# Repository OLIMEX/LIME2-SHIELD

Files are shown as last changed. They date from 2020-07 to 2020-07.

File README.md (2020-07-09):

# LIME2-SHIELD
Shield for A20-OLinuXino-LIME2 which adds Audio, CAN, microSD-card, 2x UEXT, CAN

Product page: https://www.olimex.com/Products/OLinuXino/A20/LIME2-SHIELD/open-source-hardware

## Licensee
* Hardware is released under CERN Open Hardware Licence Version 2 -
Strongly Reciprocal
* Software is released under GPL3 Licensee
* Documentation is released under CC BY-SA 3.0

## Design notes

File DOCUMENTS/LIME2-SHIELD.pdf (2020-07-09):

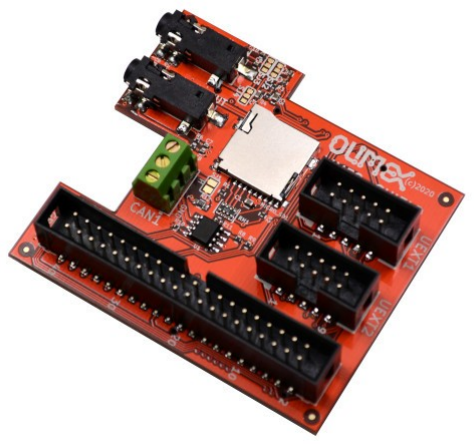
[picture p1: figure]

# LIME2-SHIELD

# User Manual

# Rev.1.0 June 2020

# olimex.com

## Table of Contents

This is possible only for the boards which has SPI Flash where uboot to be hold, as A20 can’t boot

Note that some interfaces are multiplexed with other functions and if you enable may distrub other

Now you have access to GPIO, SPI, I2C and Serial ports of A20-OLinuXino-LIME2 via Python

Next code switch on and off MOD-IO relays. MOD-IO should be connected to UEXT1. The code is

## What is LIME2-SHIELD

LIME2-SHIELD is small board which snaps on top of OLinuXino-LIME2 Linux computers and adds:
- Audio Headphone + microphone 3.5 mm connector
- Audio Line in / out connector
- Second micro SD card for data storage
- CAN driver and connector
- Two UEXT connectors with SERIAL, I2C, SPI available for users to connect UEXT modules
- 40 pin 0.1 breadboard friendly connector which can be used with IDC40 cable or Jumper wires Jwxxx

Audio-In

Headphones-Mic

UEXT-1

UEXT-2

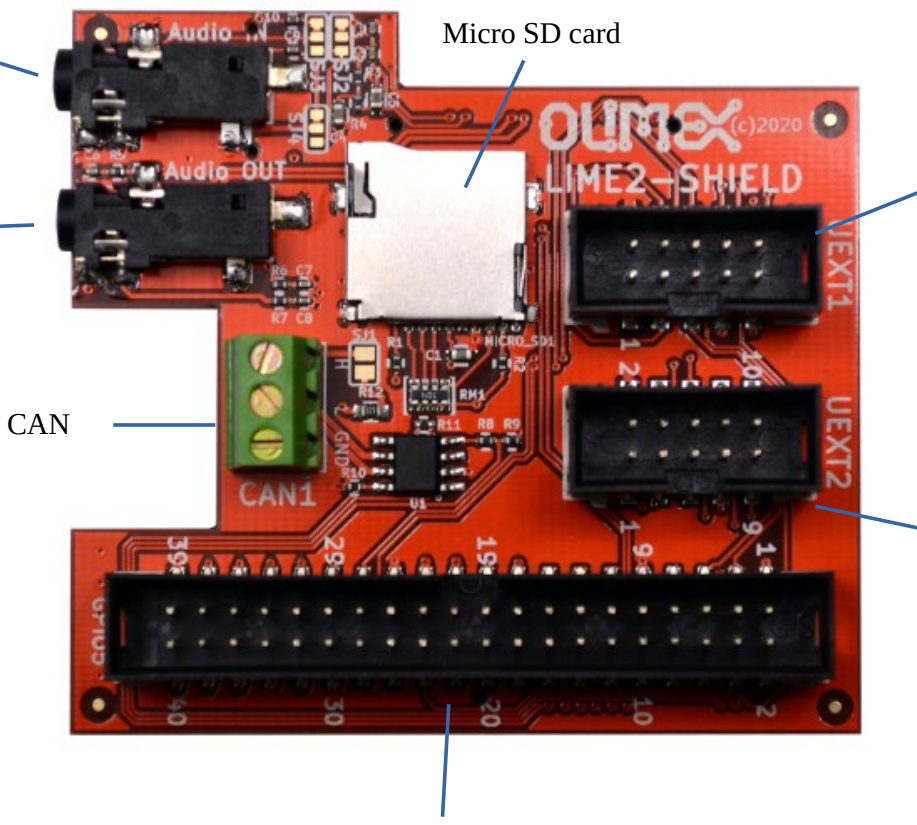
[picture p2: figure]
Micro SD card; CAN

GPIO-5

## Available signals and interfaces:

UEXT1
function | Int | Linux | A20 | A20 | Linux | Int | function
+3.3V | 1 | 2 | GND
UART4-TX | | GPIO202 | PG10 | 3 | 4 | PG11 | GPIO203 | UART4-RX
TWI2-SCL | | GPIO52 | PB20 | 5 | 6 | PB21 | GPIO53 | TWI2-SDA
SPI2-MISO | | GPIO86 | PC22 | 7 | 8 | PC21 | GPIO85 | SPI2-MOSI
SPI2-SCK | | GPIO84 | PC20 | 9 | 10 | PC19 | GPIO83 | SPI2-CS0

UEXT2
function | Int | Linux | A20 | A20 | Linux | Int | function
+3.3V | 1 | 2 | GND
UART7-TX | | GPIO276 | PI20 | 3 | 4 | PI21 | GPIO277 | | UART7-RX
TWI1-SCL | | GPIO50 | PB18 | 5 | 6 | PB19 | GPIO51 | | TWI1-SDA
SPI1-MISO | EINT31 | GPIO275 | PI19 | 7 | 8 | PI18 | GPIO274 | EINT30 | SPI1-MOSI
SPI1-SCK | EINT29 | GPIO273 | PI17 | 9 | 10 | PI16 | GPIO272 | EINT28 | SPI1-CS0

GPIO5
rPi | function | Int | Linux | A20 | A20 | Linux | Int | function | rPi
+3.3V | 1 | 2 | +5V
GPIO2 | TWI2-SDA | | GPIO53 | PB21 | 3 | 4 | +5V
GPIO3 | TWI2-SCL | | GPIO52 | PB20 | 5 | 6 | GND
GPIO4 | | | GPIO271 | PI15 | 7 | 8 | PG7 | GPIO199 | | UART3-RX | GPIO14
GND | | | | | 9 | 10 | PG6 | GPIO198 | | UART3-TX | GPIO15
GPIO17 | | EINT23 | GPIO267 | PI11 | 11 | 12 | PI3 | GPIO259 | | PWM1 | GPIO18
GPIO27 | | EINT22 | GPIO266 | PI10 | 13 | 14 | GND
GPIO22 | | | GPIO263 | PI7 | 15 | 16 | PE6 | GPIO136 | | | GPIO23
+3.3V | | | | | 17 | 18 | PE5 | GPIO135 | | | GPIO24
GPIO10 | SPI2-MOSI | | GPIO85 | PC21 | 19 | 20 | GND
GPIO9 | SPI2-MISO | | GPIO86 | PC22 | 21 | 22 | PE4 | GPIO132 | | | GPIO25
GPIO11 | SPI2-SCK | | GPIO84 | PC20 | 23 | 24 | PC19 | GPIO83 | | SPI2-CS0 | GPIO8
GND | | | | | 25 | 26 | PH14 | GPIO238 | EINT14 | | GPIO7
GPIO0 | TWI1-SDA | | GPIO51 | PB19 | 27 | 28 | PB18 | GPIO50 | | TWI1-SCL | GPIO1
GPIO5 | | | GPIO129 | PE1 | 29 | 30 | GND
GPIO6 | | | GPIO136 | PE8 | 31 | 32 | PH13 | GPIO237 | EINT13 | | GPIO12
GPIO13 | | | GPIO137 | PE9 | 33 | 34 | GND
GPIO19 | | | GPIO138 | PE10 | 35 | 36 | PH12 | GPIO236 | EINT12 | | GPIO16
GPIO26 | | | GPIO139 | PE11 | 37 | 38 | PH11 | GPIO235 | EINT11 | | GPIO20
GND | | | | | 39 | 40 | PH10 | GPIO234 | EINT10 | | GPIO21

## Linux images for SD card booting:

Olimex has it own image build scripts available at GitHub. (https://github.com/OLIMEX/olimage)
The pre-built and tested images can be found at: images.olimex.com. There are release and testing folders, use the stabile images from release only. Testing images are not tested completely and you can use on your own risk.
We support Ubuntu and Debian minimal and basic images. The list of the packages is in the .lst file. For all examples below we use Ubuntu minimal image (http://images.olimex.com/release/a20/) .
To make your own SD card download the image and un-archive it with 7z archiver. (https://www.7-zip.org/)
Do not use DD for image write to SD-card, use balenaEtcher (https://www.balena.io/etcher/) to write the image to minimum 8GB Class 10 SD card like this one. (https://www.olimex.com/Products/Components/Storage/MICRO-SD-CLASS10/)
We strongly suggest you to use Olimex official images as they are 100% tested and know to work with all board features.
If you have USB cable you can insert it to USB-OTG connector of A20-OLinuXino-LIME2 and run any serial terminal:

### $ sudo minicom -D /dev/ttyACM0

Initial login is user: root or olimex, password: olimex
When new Linux image is released you do not need to download the image and write to the card, but only to run:

### $ sudo apt update $ sudo apt upgrade $ sudo reboot now

This way you will have always the latest version of Linux kernel and uboot.

## Boot from eMMC:

If you have A20-OLinuXino-LIME2 with eMMC memory you can make your boot from eMMC instead of SD-card to do this you have to boot from SD-card then execute:

### $ olinuxino-sd-to-emmc

after the script finish the SD-card image is copied to eMMC, then remove the SD-card and reboot.

## Boot from SATA:

This is possible only for the boards which has SPI Flash where uboot to be hold, as A20 can’t boot from SATA directly.
When you boot from SD-card you run:

### $ olinuxino-sd-to-sata

This script will write uboot to SPI Flash and Linux file system to SATA drive.

## Linux overlays:

To enable the different interfaces use:

### $ olinuxino-overlay

This will give you access to all overlays for the board.
Note that some interfaces are multiplexed with other functions and if you enable may distrub other functionality.

All overlays do not fit on single screen so you have to scroll down to see all options.

## Display overlays:

You can use olinuxino-display script to select your default LCD display.

### $ olinuxino-display

## Installing C:

The minimal Linux image comes with no C compiler installed so you need to install yourself:

### $ sudo apt install gcc

then you can compile your c code with

### $ gcc test.c -o program

and allow program to be executed:

### $ chmod +777 program

then run it with

### $ ./program

## Installing pyA20Lime2:

First you need to install Python

### $ sudo apt install python3 $ sudo apt install python3-venv python3-pip $ python3 -m pip install --upgrade pip setuptools wheel $ sudo su # pip3 install pyA20Lime2

Now you have access to GPIO, SPI, I2C and Serial ports of A20-OLinuXino-LIME2 via Python package pyA20Lime2. (https://pypi.org/project/pyA20Lime2/)

## Software access to board resources:

## GPIO in command line:

GPIOs are digital inputs or outputs which are available for the user. By default none of them is enabled. You can see the available GPIOs with the command:

### $ls sys/class/gpio

to enable GPIO you have to export it and to assign it as input or output
Let for example attach LED to GPIO5 connector pin.7 A20 port PI15 and GPIO5 connector pin.9 (GND). We need to connect negative (cathode) lead of the LED to GND (GPIO5.pin9) and the positive LED positive (anode) lead through 470 ohm resistor to A20.PI15 (GPIO5.pin7). The 470 ohm resistor is necessary to limit the current which will flow through LED.
Here is picture of our setup:

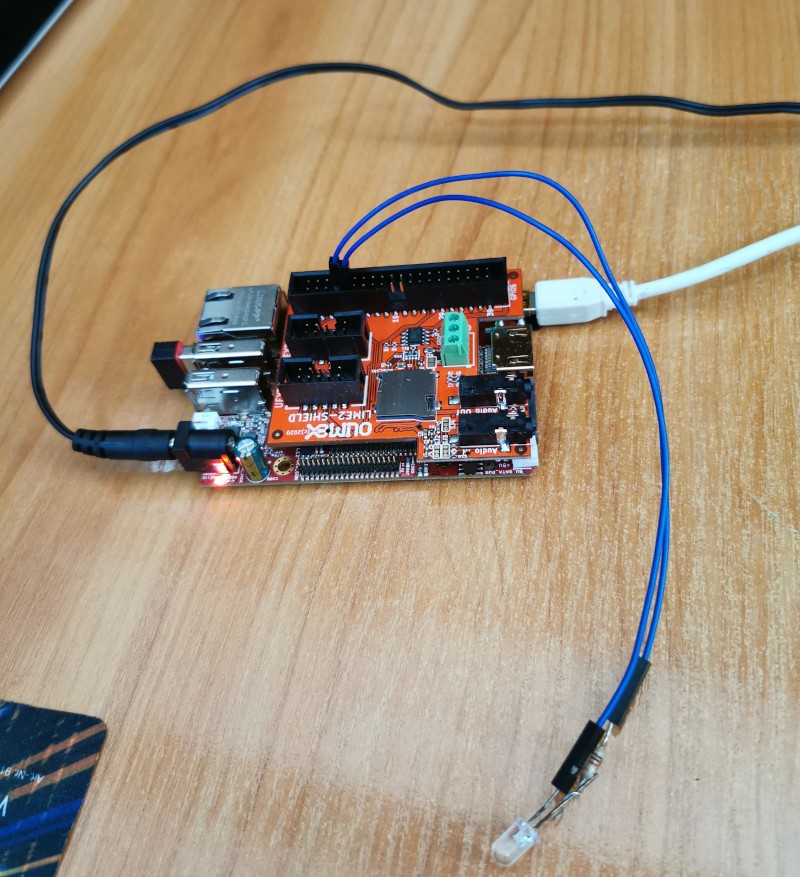
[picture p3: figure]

Now to light on the LED we have to export A20.PI15 then to make it output and write 1 in it which will bring 3.3V to the A20.PI15 pin which voltage will light the LED on.
To deal with the GPIOs we need to have superuser rights, so we start with:

### $ sudo su

we will be asked for the password, then the prompt will change to #

### # echo 271 > /sys/class/gpio/export

now we can check if gpio271 is already available with

### # ls sys/class/gpio

and we see the gpio271 is already listed now we have to define it as output:

### # echo out > /sys/class/gpio/gpio271/direction

now we have GPIO271 defined as output we can change it state with

### # echo 1 > /sys/class/gpio/gpio271/value

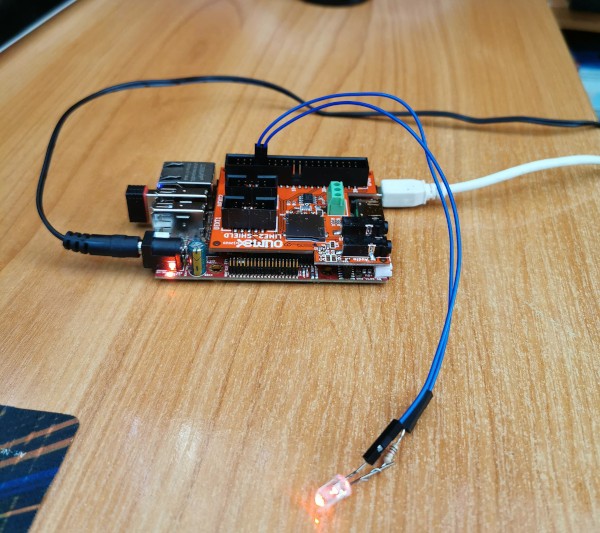
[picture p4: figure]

And the LED is lighting:

to turn if off we type

### # echo 0 > /sys/class/gpio/gpio271/value

Let now make GPIO271 as input

### # echo in > /sys/class/gpio/gpio271/direction

let connect A20.PI15 GPIO5.pin7 to GND GPIO5.pin9 :

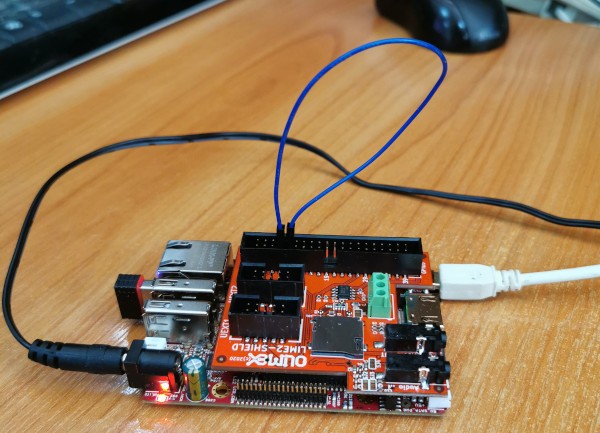
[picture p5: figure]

now we check the value with:

### #cat /sys/class/gpio/gpio271/value

we see 0. If we connect A20.PI15 GPIO5.pin7 to 3.3V GPIO5.pin17 and execute again cat command we see 1
Where the number 271 comes from? It’s Linux numbering the number corresponding to the port is calculated as PA starts from 0, PB starts from 32,... PI is staring from 8*32 = 256 so PI15 is 256+15 = 271

## GPIO with C code:

Here below is example how to drive GPIOs in C code. The sources are available on GitHub.

### include <stdio.h> #include <fcntl.h> #include <string.h>

### int main() {

char s_out[] = "out";
char s_gpio[] = "271";
char s_0[] = "0";
char s_1[] = "1";
int fd;

### //export GPIO271

### if((fd=open("/sys/class/gpio/export",O_WRONLY))<0) {

printf("can't open export GPIO\r\n"); return(1);

### } else { if(write(fd,s_gpio,strlen(s_gpio))<0) {

printf("can't write to export GPIO\r\n"); return(1);
}
printf("GPIO271 is exported\r\n");

### if(close(fd)<0) {

printf("can't close export GPIO\r\n"); return(1);
}
}

### //set as output GPIO271

### if((fd=open("/sys/class/gpio/gpio271/ direction",O_WRONLY))<0) {

printf("can't open GPIO direction\r\n"); return(1);

### } else { if(write(fd,s_out,strlen(s_out))<0) {

printf("can't write GPIO direction\r\n"); return(1);
}
printf("GPIO271 is set as output\r\n");

### if(close(fd)<0) {

printf("can't close GPIO direction\r\n"); return(1);
}
}

### //toggle GPIO271

### if((fd=open("/sys/class/gpio/gpio271/value",O_WRONLY))<0) {

printf("can't open GPIO value\r\n");
return(1);

### } else {

### while(1) {

### if(write(fd,s_1,strlen(s_1))<0) {

printf("can't write GPIO value\r\n"); return(1);
}

### if(write(fd,s_0,strlen(s_0))<0) {

printf("can't write GPIO value\r\n"); return(1);
}
};

### if(close(fd)<0)

return(1);
}

}

## GPIO with Python:

Let use same setup LED connected to GPIO5 connector pin.7 A20 port PI15 and GPIO5 connector pin.9 (GND). We need to connect negative (cathode) lead of the LED to GND (GPIO5.pin9) and the positive LED positive (anode) lead through 470 ohm resistor to A20.PI15 (GPIO5.pin7). The 470 ohm resistor is necessary to limit the current which will flow through LED.

### !/usr/bin/env python from pyA20Lime2.gpio import gpio from pyA20Lime2.gpio import port from pyA20Lime2.gpio import connector

### gpio.init() #Initialize module. Always called first

### gpio.setcfg(port.PI15, gpio.OUTPUT) #Configure LED1 as output

gpio.setcfg(port.PI15, 1) | #This is the same as

### above

### gpio.output(port.PI15, gpio.HIGH) #Set PI15 High (3.3V) and Light on LED

gpio.output(port.PI15, 1) | #same as above
gpio.output(port.PI15, gpio.LOW) | #Set PI15 Low (0V)

### Light off

gpio.output(port.PI15, 0) | #same as above
gpio.setcfg(port.PI15, gpio.INPUT) | #Configure PI15 as

### input

gpio.setcfg(port.PI15, 0) | #Same as above
gpio.pullup(port.PI15, 0) | #Clear pullups

### gpio.pullup(port.PI15, gpio.PULLDOWN) #Enable pull-down gpio.pullup(port.PI15, gpio.PULLUP) #Enable pull-up

### if gpio.input(port.PI15) == 1: # this will be executed when input is HIGH i.e. 3.3V else: # this will be executed when input is LOW i.e. 0V

## I2C in command line

You can detect where your device is connected by using i2cdetect command. For instance if you have connected MOD-IO to UEXT1 connector and run i2cdetect you will see it’s address 0x58 active:

### $ sudo i2cdetect -r -y 2 0 1 2 3 4 5 6 7 8 9 a b c d e f

00: | -- -- -- -- -- -- -- -- -- -- -- -- --
10: -- -- -- -- -- -- -- -- -- -- -- -- -- -- -- --20: -- -- -- -- -- -- -- -- -- -- -- -- -- -- -- --30: -- -- -- -- -- -- -- -- -- -- -- -- -- -- -- --40: -- -- -- -- -- -- -- -- -- -- -- -- -- -- -- --50: -- -- -- -- -- -- -- -- 58 -- -- -- -- -- -- --60: -- -- -- -- -- -- -- -- -- -- -- -- -- -- -- --70: -- -- -- -- -- -- -- --

### Then you can drive relays on and off:

### $ sudo i2cset -y 2 0x58 0x10 0x01

this will swtich on RELAY1, to switch it off:

### $ sudo i2cset -y 2 0x58 0x10 0x00

if you want to read MOD-IO status you can use i2transfer:

### $ sudo i2ctransfer -y 2 w1@0x58 0x20 r1

0x00

Now connect wire from IN1 left side to GND (for instance AIN-2 connector has AGND) and right side to +3.3-12V for instance AIN-2 connector has 3.3V)
if you run again i2ctransfer command the returned value will be 0x01:

### $ sudo i2ctransfer -y 2 w1@0x58 0x20 r1

0x01

## I2C in C code

Here is example how to use I2C with C. The source is available on GitHub. main.c

### include <stdio.h> #include <linux/i2c.h> #include <linux/i2c-dev.h> #include <fcntl.h> #include <stdlib.h> #include <unistd.h> #include <sys/ioctl.h> #include <string.h> #include "i2c.h"

### int main(int argc, char **argv)

{

### //switch on MOD-IO relay 1

int file;
unsigned char buffer[2], address;

address = 0x58;
buffer[0] = 0x10;
buffer[1] = 0x01;
I2C_Open(&file, address);
I2C_Send(&file, buffer, 2); I2C_Close(&file);

return 0;
}

i2c.c

### include <stdio.h> #include <linux/i2c.h> #include <linux/i2c-dev.h> #include <fcntl.h> #include <stdlib.h> #include <unistd.h> #include <sys/ioctl.h>

### #include <string.h>

### void I2C_Open(int *file, unsigned char address)

{
*file = (int)open("/dev/i2c-2", O_RDWR);

### if(*file < 0)

{
perror("Failed to open I2C"); exit(1);
}

### else

{

### if(ioctl(*file, I2C_SLAVE, address) < 0)

{
perror("Failed to access I2C bus"); exit(1);
}
}
}

### void I2C_Close(int *file)

{
close(*file);
}

### void I2C_Send(int *file, char *buffer, int num)

{
int bytes;
bytes = write(*file, buffer, num);

### if(bytes != num)

{
perror("Failed to send data"); exit(1);
}
}

### void I2C_Read(int *file, unsigned char *buffer, int num)

{
int bytes;
bytes = read(*file, buffer, num);

### if(bytes != num)

{
perror("Failed to read data"); exit(1);
}
}

i2c.h

### ifndef I2C_H #define I2C_H

void I2C_Open(int *file, unsigned char address);
void I2C_Send(int *file, unsigned char *buffer, int num); void I2C_Read(int *file, unsigned char *buffer, int num); void I2C_Close(int *file);

### #endif

makefile

### CC = gcc CFLAG = -c -Wall

### all: i2c-demo

### i2c-demo: i2c.o main.o $(CC) i2c.o main.o -o mod-io

### main.o: main.c $(CC) $(CFLAG) main.c

### i2c.o: i2c.c $(CC) $(CFLAG) i2c.c

### clean: rm -rf *.o i2c-demo

## I2C in Python

Next code switch on and off MOD-IO relays. MOD-IO should be connected to UEXT1. The code is available on GitHub.

### from pyA20Lime2 import i2c i2c.init("/dev/i2c-2")

### i2c.open(0x58) i2c.write([0x10, 0x01]) # switich ON relay1 i2c.close()

### i2c.open(0x58) i2c.write([0x10, 0x00]) # switich OFF relay1 i2c.close()

### i2c.open(0x58)

i2c.write([0x20]) | # read IN1..4 state

### value = i2c.read(1) i2c.close()

## CAN in command line

LIME2-SHIELD has CAN driver so you can connect to CAN bus.

### $ ifconfig -a can0: flags=128<NOARP> mtu 16 unspec 00-00-00-00-00-00-00-00-00-00-00-00-00-00-00-00 txqueuelen 10 ) RX packets 0 bytes 0 (0.0 B) RX errors 0 dropped 0 overruns 0 frame 0 TX packets 0 bytes 0 (0.0 B) TX errors 0 dropped 0 overruns 0 carrier 0 collisions 0 device interrupt 59

To use CAN interface you can install can-utils and setup the CAN interface:

### $ sudo apt-get install can-utils $ ip link set can0 down $ ip link set can0 type can bitrate 100000 triple-sampling on loopback off $ ip link set can0 up

Now conect A20-CAN to the CAN network two wire interface.

To send a packet over CAN use :

### cansend <can_interface> <packet>

### For instance:

### $ cansend can0 5AA#10.10.10

To sniff for CAN network messages you can use candump :

### $ candump can0

Now you can log your car CAN networking messages and interpret them. There is plenty of info on the web about the different CAN messages which are exchanged on car CAN bus.

## CAN in C code

Kernel code documentation https://www.kernel.org/doc/Documentation/networking/can.txt C code Examples from GitHub (https://github.com/craigpeacock/CAN-Examples)
cansend.c

#include <stdio.h>

#include <stdlib.h>

#include <string.h>

#include <unistd.h>

#include <net/if.h>

#include <sys/ioctl.h>

#include <sys/socket.h>

#include <linux/can.h>

#include <linux/can/raw.h>

int main(int argc, char **argv) {
int s;
struct sockaddr_can addr;
struct ifreq ifr;
struct can_frame frame;

printf("CAN Sockets Demo\r\n");

if ((s = socket(PF_CAN, SOCK_RAW, CAN_RAW)) < 0) { perror("Socket");
return 1;
}

strcpy(ifr.ifr_name, "can0" ); ioctl(s, SIOCGIFINDEX, &ifr);

memset(&addr, 0, sizeof(addr));
addr.can_family = AF_CAN;
addr.can_ifindex = ifr.ifr_ifindex;

if (bind(s, (struct sockaddr *)&addr, sizeof(addr)) < 0) { perror("Bind");
return 1;
}

frame.can_id = 0x555;
frame.can_dlc = 5;
sprintf(frame.data, "Hello");

if (write(s, &frame, sizeof(struct can_frame)) != sizeof(struct can_frame)) { perror("Write");
return 1;
}

if (close(s) < 0) {
perror("Close");
return 1;
}

return 0;
}

canreceive.c

#include <stdio.h>

#include <stdlib.h>

#include <string.h>

#include <unistd.h>

#include <net/if.h>

#include <sys/ioctl.h>

#include <sys/socket.h>

#include <linux/can.h>

#include <linux/can/raw.h>

int main(int argc, char **argv) {
int s, i;
int nbytes;
struct sockaddr_can addr;
struct ifreq ifr;
struct can_frame frame;

printf("CAN Sockets Receive Demo\r\n");

if ((s = socket(PF_CAN, SOCK_RAW, CAN_RAW)) < 0) { perror("Socket");
return 1;
}

strcpy(ifr.ifr_name, "can0" ); ioctl(s, SIOCGIFINDEX, &ifr);

memset(&addr, 0, sizeof(addr));
addr.can_family = AF_CAN;
addr.can_ifindex = ifr.ifr_ifindex;

if (bind(s, (struct sockaddr *)&addr, sizeof(addr)) < 0) { perror("Bind");
return 1;
}

nbytes = read(s, &frame, sizeof(struct can_frame));

if (nbytes < 0) {
perror("Read");
return 1;
}

printf("0x%03X [%d] ",frame.can_id, frame.can_dlc);

for (i = 0; i < frame.can_dlc; i++)
printf("%02X ",frame.data[i]);

printf("\r\n");

if (close(s) < 0) {
perror("Close");
return 1;
}

return 0;
}

## SPI in Python

SPI communication in Python:

### #!/usr/bin/env python

### from pyA20Lime2 import spi

### spi.open("/dev/spidev2.0") #Open SPI device with default settings # mode : 0 # speed : 100000kHz # delay : 0 # bits-per-word: 8

### Different ways to open device spi.open("/dev/spidev2.0", mode=1) spi.open("/dev/spidev2.0", mode=2, delay=0)

spi.open("/dev/spidev2.0", mode=3, delay=0,

### bits_per_word=8)

spi.open("/dev/spidev2.0", mode=0, delay=0,

### bits_per_word=8, speed=100000)

### spi.write([0x01, 0x02]) #Write 2 bytes to slave device spi.read(2) #Read 2 bytes from slave device spi.xfer([0x01, 0x02], 2) #Write 2 byte and then read 2

bytes.

### spi.close() #Close SPI bus

## Revision History

Revision 1.0 June 2020

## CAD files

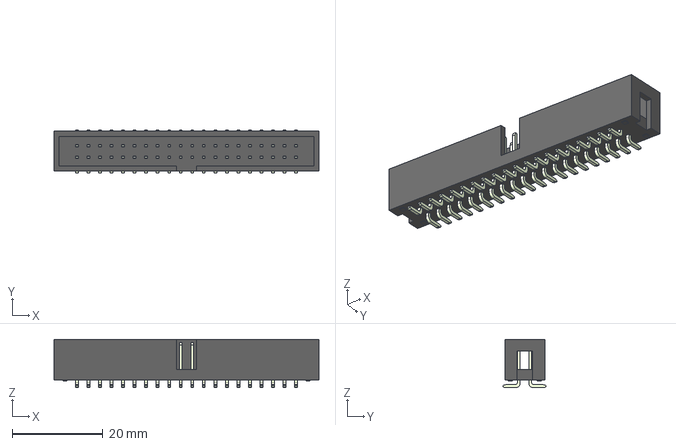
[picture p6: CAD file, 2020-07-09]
HARDWARE/Lime2-SHIELD-Rev.C/3d/GBH254SMT-40(B-V-40-LF).stp
58.4 x 9.50 x 10.6 mm

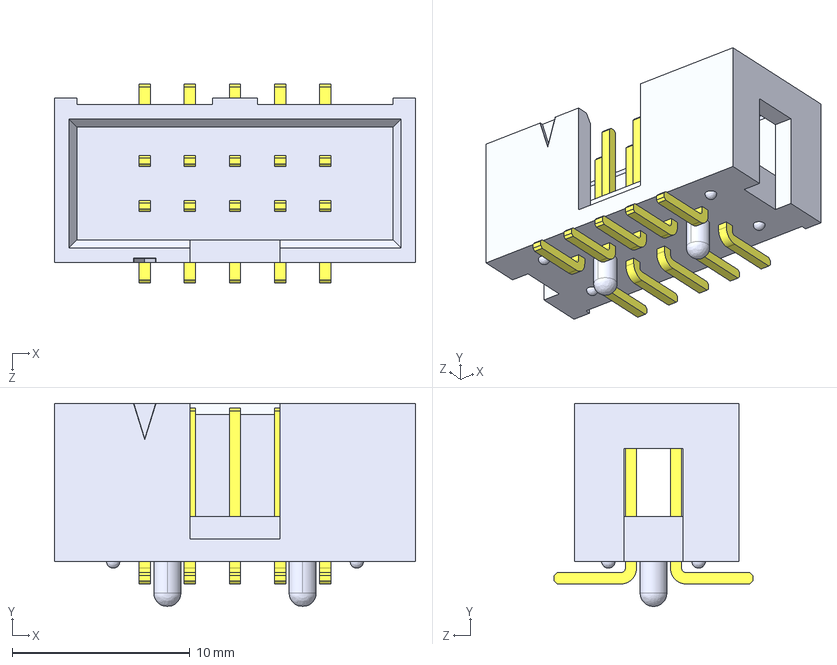
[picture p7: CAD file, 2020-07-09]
HARDWARE/Lime2-SHIELD-Rev.C/3d/UEXT-SMD.STEP
20.3 x 11.4 x 11.2 mm
User Library-HTST-105-01-F-DV-A__HTST-105-01-DV-A_header
User Library-HTST-105-01-F-DV-A__HTST-First_Position_Indicator
User Library-HTST-105-01-F-DV-A__T-1S6-05-01-DV_

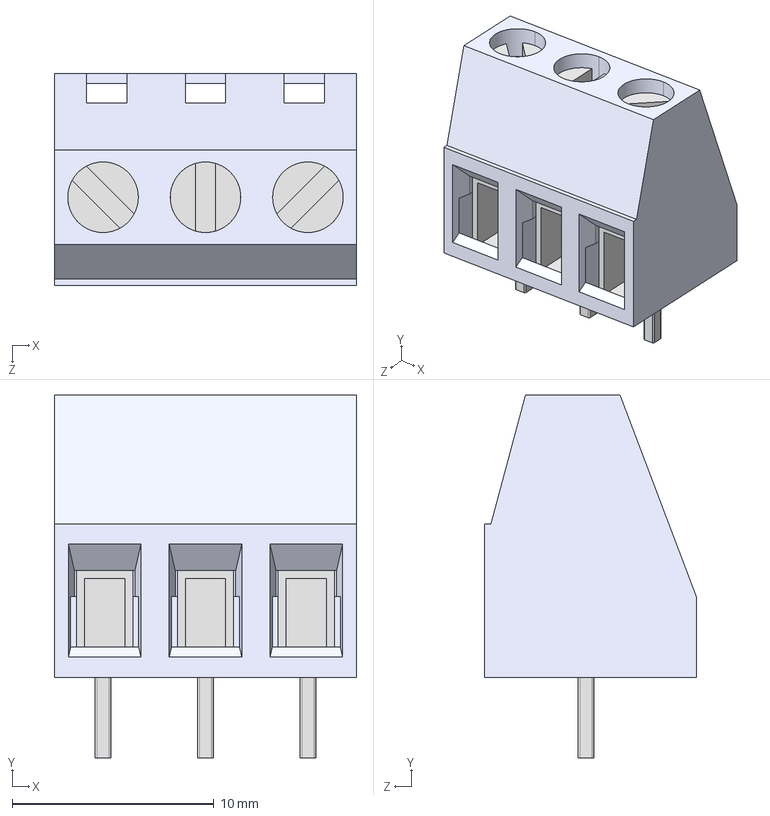
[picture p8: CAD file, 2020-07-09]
HARDWARE/Lime2-SHIELD-Rev.C/3d/klema-5mm-3pin.step
15.0 x 18.0 x 10.5 mm

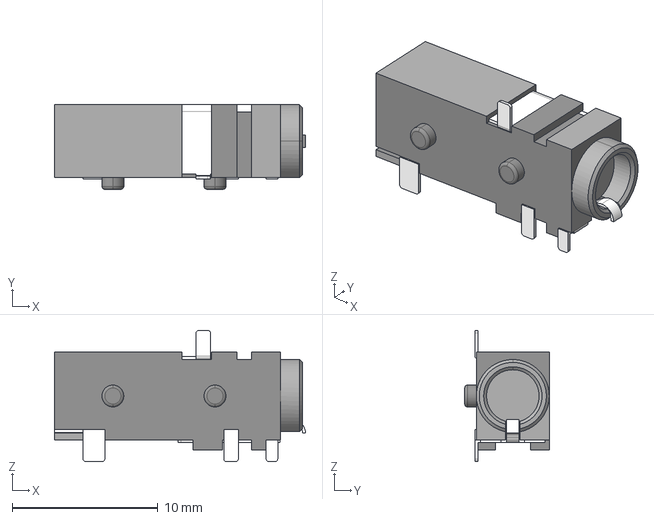
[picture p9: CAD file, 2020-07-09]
HARDWARE/Lime2-SHIELD-Rev.C/3d/sj-43514-smt-tr.stp
17.2 x 5.80 x 9.00 mm

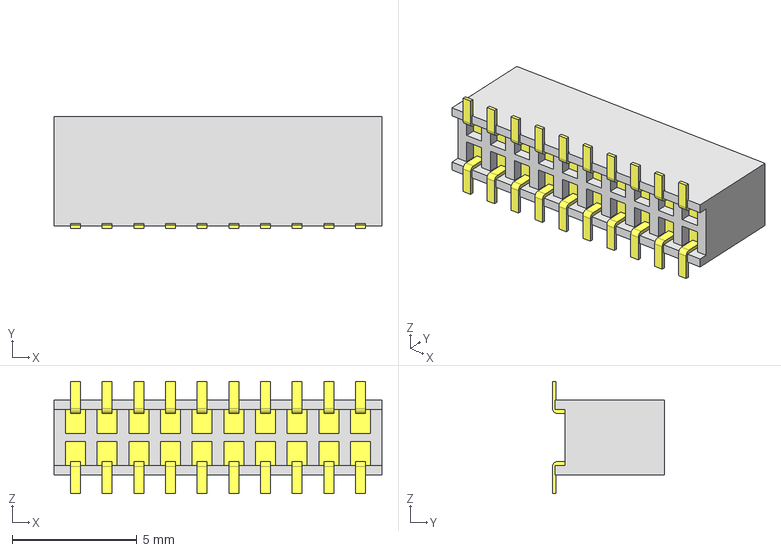
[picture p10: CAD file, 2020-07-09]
HARDWARE/Lime2-SHIELD-Rev.C/3d/YA-V36P-2X10-Amphenol_ICC(FCI)_20021321-00020T4LF.stp
13.2 x 4.50 x 4.50 mm
_20021321-00020T4LF_body
_20021321-00020T4LF_pins

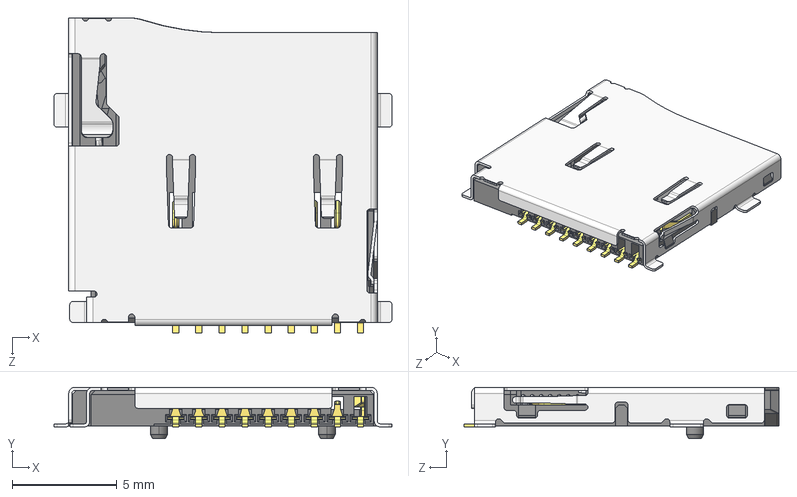
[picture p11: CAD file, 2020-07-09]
HARDWARE/Lime2-SHIELD-Rev.C/3d/TFC-WPAPR-08---112J-TXAR-R_C_1-1.STEP
16.1 x 2.45 x 15.0 mm

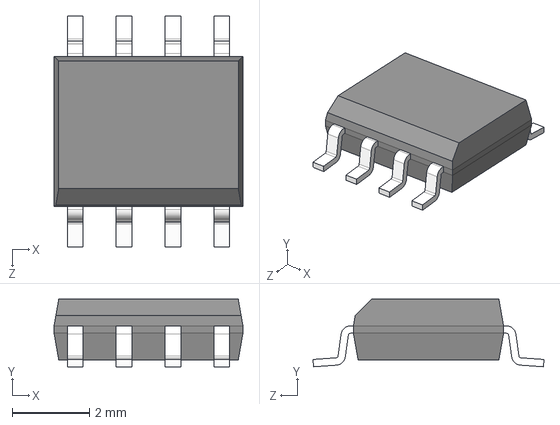
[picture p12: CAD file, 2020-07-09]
HARDWARE/Lime2-SHIELD-Rev.C/3d/SO-8_150mil---SN65HVDA1050AQDRQ1.STEP
4.90 x 1.75 x 5.99 mm

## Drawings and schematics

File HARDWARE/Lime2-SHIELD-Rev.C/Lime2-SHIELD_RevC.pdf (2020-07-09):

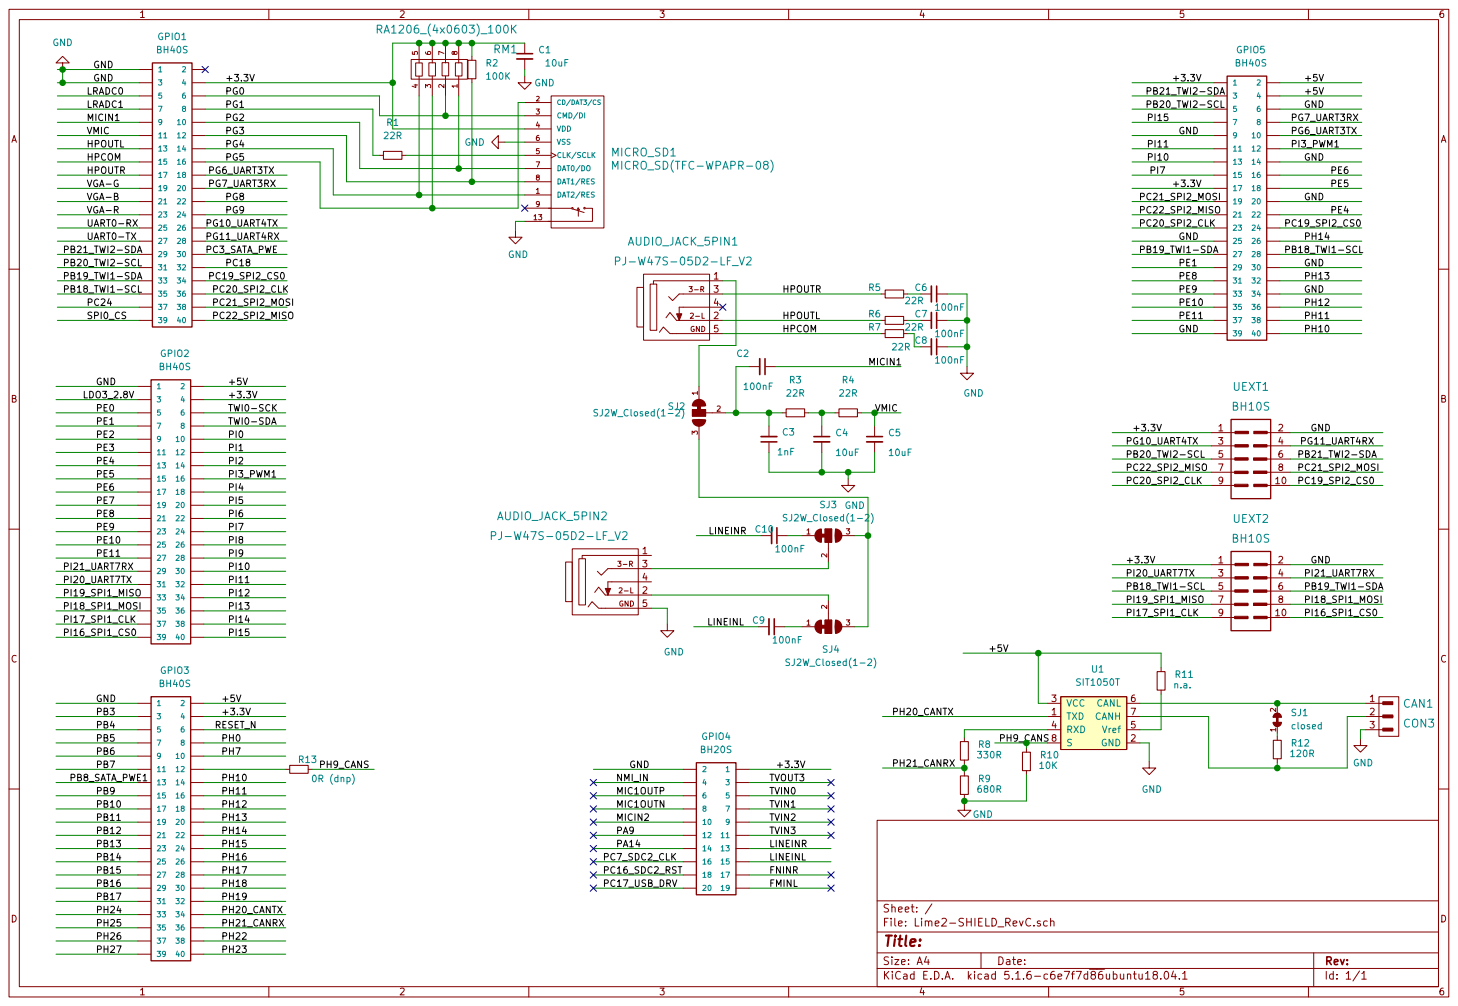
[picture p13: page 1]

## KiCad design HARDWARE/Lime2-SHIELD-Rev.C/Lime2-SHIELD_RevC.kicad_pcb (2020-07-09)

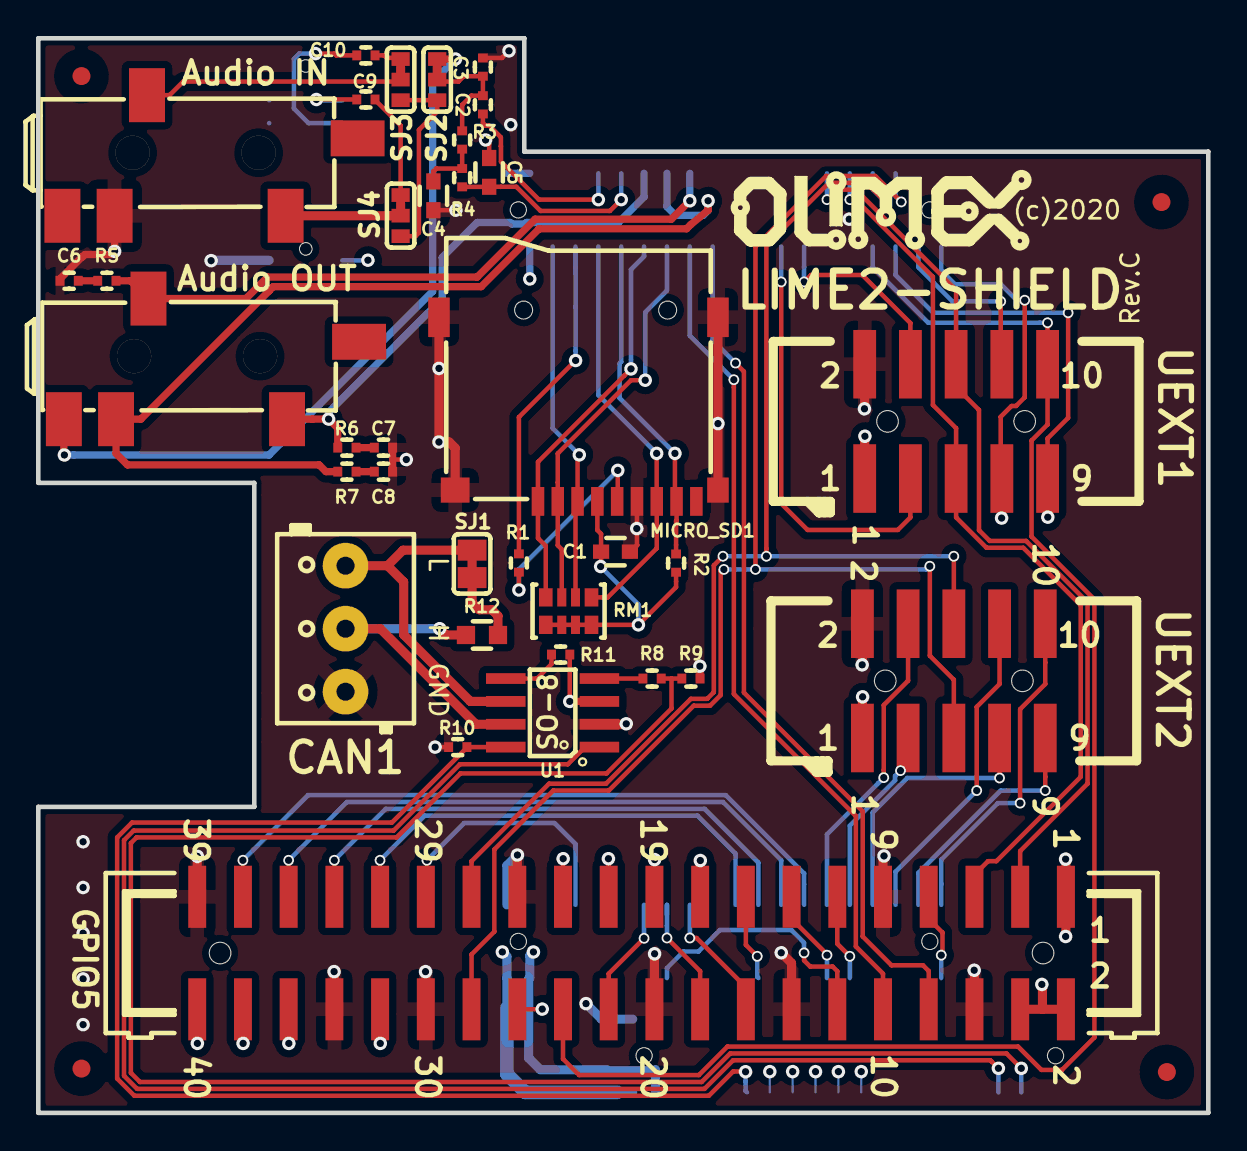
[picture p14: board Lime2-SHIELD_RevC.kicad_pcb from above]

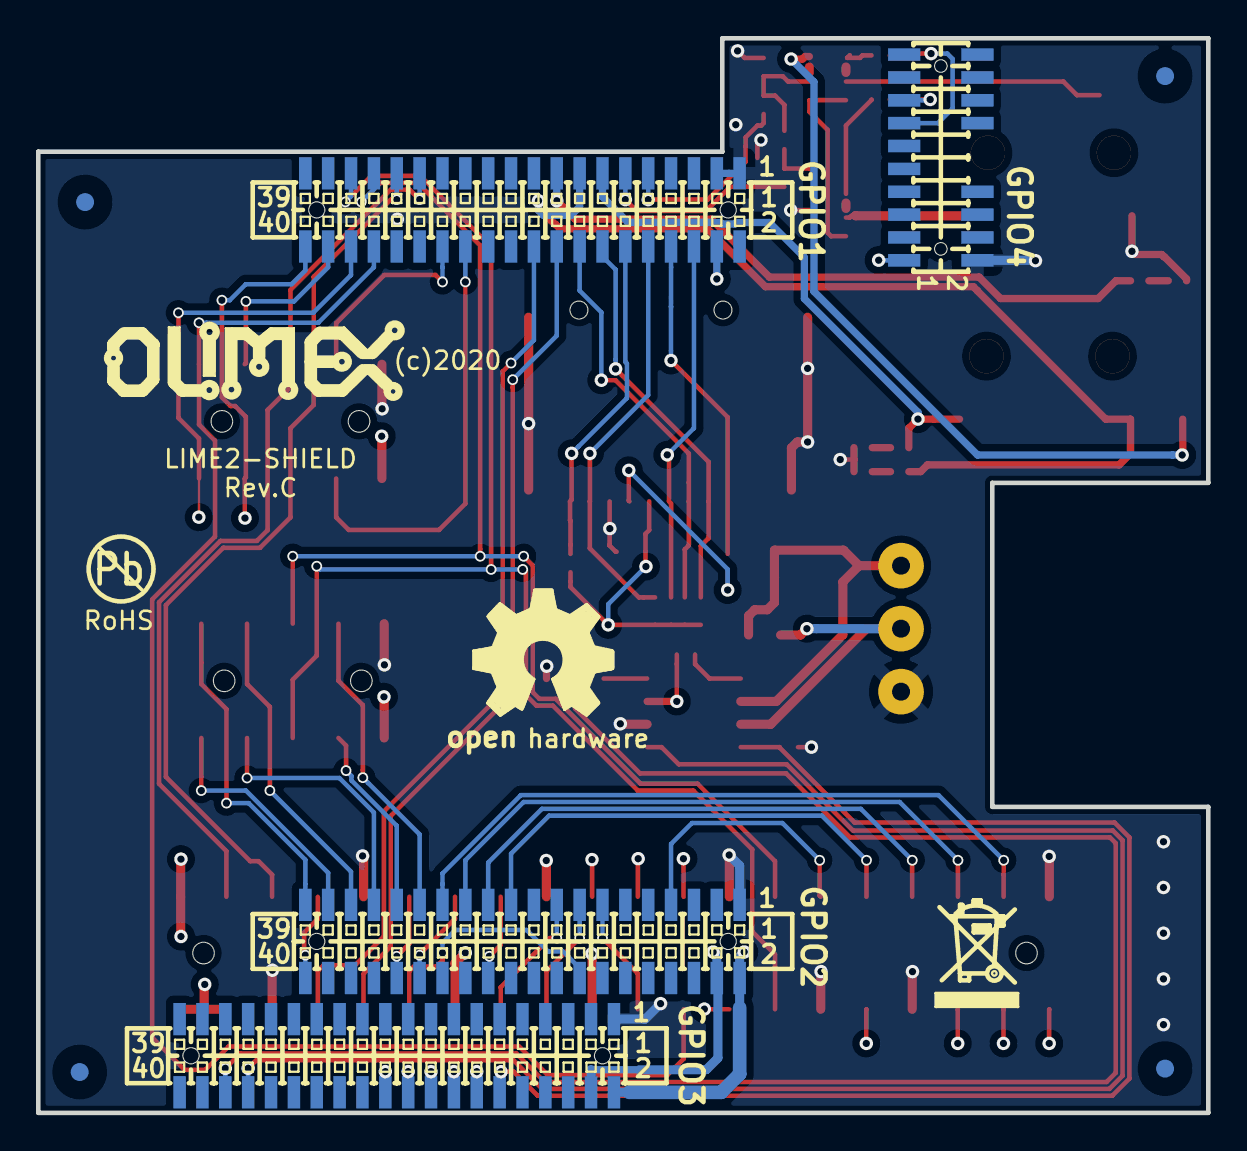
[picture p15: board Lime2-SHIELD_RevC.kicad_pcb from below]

Board: 4 copper layers, 65.0 x 59.7 mm, 47 parts (8 on the bottom side), 72 nets.

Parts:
AUDIO_JACK_5PIN1, AUDIO_JACK_5PIN2: PJ-W47S-05D2-LF_V2; PJ-W47S-05D2-LF_5PIN_V2
C1, C4, C5: 10uF; C_0603_5MIL_DWS
C2, C6, C7, C8, C9, C10: 100nF; C_0402_5MIL_DWS
C3: 1nF; C_0402_5MIL_DWS
CAN1: CON3; TB3-3.5mm
GPIO1, GPIO2, GPIO3: BH40S; GPH127SMT-02X20(PA-V16X-2X20-LF)_Drill_0.9mm
GPIO4: BH20S; GPCB127SMT-02X10(YA-V36P-2X10-LF)
GPIO5: BH40S; GBH-254-SMT-40_Shorten_Pads
MICRO_SD1: MICRO_SD(TFC-WPAPR-08); TFC-WPAPR-08
R1, R3, R4, R5, R6, R7: 22R; R_0402_5MIL_DWS
R2: 100K; R_0402_5MIL_DWS
R8, R10: 10K; R_0402_5MIL_DWS
R9: 22K; R_0402_5MIL_DWS
R11: n.a.; R_0402_5MIL_DWS
R12: 120R; R_0603_5MIL_DWS
RM1: RA1206_(4x0603)_100K; R_MATRIX_4_KICAD
Ref*: Val**; Fiducial1x3_transp
Ref*#2, Ref*#3, Ref*#4, Ref*#5, Ref*#6, Ref*#7, Ref*#8: Val**; Fiducial1x3_transp
SJ1: open; SJ_Closed
SJ2, SJ3, SJ4: SJ2W_Closed(1-2); SJ_2_SMALL_12_TIED
U1: SIT1050T; SO-8
UEXT1, UEXT2: BH10S; GBH-254-SMT-10_Smaller

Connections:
/+3.3V: C1.1, GPIO1.4, GPIO2.4, GPIO3.4, GPIO4.1, GPIO5.1, GPIO5.17, MICRO_SD1.4, R2.1, RM1.5, RM1.6, RM1.7, RM1.8, UEXT1.1, UEXT2.1
/+5V: GPIO2.2, GPIO3.2, GPIO5.2, GPIO5.4, R11.1, U1.3
/HPCOM: AUDIO_JACK_5PIN1.5, GPIO1.15, R7.2
/HPOUTL: AUDIO_JACK_5PIN1.2, GPIO1.13, R6.2
/HPOUTR: AUDIO_JACK_5PIN1.3, GPIO1.17, R5.2
/LINEINL: C9.2, GPIO4.15
/LINEINR: C10.2, GPIO4.13
/MICIN1: C2.1, GPIO1.9
/PB18_TWI1-SCL: GPIO1.35, GPIO5.28, UEXT2.5
/PB19_TWI1-SDA: GPIO1.33, GPIO5.27, UEXT2.6
/PB20_TWI2-SCL: GPIO1.31, GPIO5.5, UEXT1.5
/PB21_TWI2-SDA: GPIO1.29, GPIO5.3, UEXT1.6
/PC19_SPI2_CS0: GPIO1.34, GPIO5.24, UEXT1.10
/PC20_SPI2_CLK: GPIO1.36, GPIO5.23, UEXT1.9
/PC21_SPI2_MOSI: GPIO1.38, GPIO5.19, UEXT1.8
/PC22_SPI2_MISO: GPIO1.40, GPIO5.21, UEXT1.7
/PE1: GPIO2.7, GPIO5.29
/PE4: GPIO2.13, GPIO5.22
/PE5: GPIO2.15, GPIO5.18
/PE6: GPIO2.17, GPIO5.16
/PE8: GPIO2.21, GPIO5.31
/PE9: GPIO2.23, GPIO5.33
/PE10: GPIO2.25, GPIO5.35
/PE11: GPIO2.27, GPIO5.37
/PG0: GPIO1.6, MICRO_SD1.3, RM1.2
/PG1: GPIO1.8, R1.2
/PG2: GPIO1.10, MICRO_SD1.7, RM1.1
/PG3: GPIO1.12, MICRO_SD1.8, R2.2
/PG4: GPIO1.14, MICRO_SD1.1, RM1.4
/PG5: GPIO1.16, MICRO_SD1.2, RM1.3
/PG6_UART3TX: GPIO1.18, GPIO5.10
/PG7_UART3RX: GPIO1.20, GPIO5.8
/PG10_UART4TX: GPIO1.26, UEXT1.3
/PG11_UART4RX: GPIO1.28, UEXT1.4
/PH9_CANS: GPIO3.12, R10.1, U1.8
/PH10: GPIO3.14, GPIO5.40
/PH11: GPIO3.16, GPIO5.38
/PH12: GPIO3.18, GPIO5.36
/PH13: GPIO3.20, GPIO5.32
/PH14: GPIO3.22, GPIO5.26
/PH20_CANTX: GPIO3.34, U1.1
/PH21_CANRX: GPIO3.36, R8.2, R9.1
/PI3_PWM1: GPIO2.16, GPIO5.12
/PI7: GPIO2.24, GPIO5.15
/PI10: GPIO2.30, GPIO5.13
/PI11: GPIO2.32, GPIO5.11
/PI15: GPIO2.40, GPIO5.7
/PI16_SPI1_CS0: GPIO2.39, UEXT2.10
/PI17_SPI1_CLK: GPIO2.37, UEXT2.9
/PI18_SPI1_MOSI: GPIO2.35, UEXT2.8
/PI19_SPI1_MISO: GPIO2.33, UEXT2.7
/PI20_UART7TX: GPIO2.31, UEXT2.3
/PI21_UART7RX: GPIO2.29, UEXT2.4
/VMIC: C5.1, GPIO1.11, R4.1
GND: AUDIO_JACK_5PIN2.5, C1.2, C3.1, C4.2, C5.2, C6.1, C7.1, C8.1, CAN1.3, GPIO1.1, GPIO1.3, GPIO2.1, GPIO3.1, GPIO4.2, GPIO5.6, GPIO5.9, GPIO5.14, GPIO5.20, GPIO5.25, GPIO5.30, GPIO5.34, GPIO5.39, MICRO_SD1.6, MICRO_SD1.10, MICRO_SD1.11, MICRO_SD1.12, MICRO_SD1.13, R9.2, R10.2, U1.2, UEXT1.2, UEXT2.2
unnamed: AUDIO_JACK_5PIN1.1, SJ2.1
unnamed: AUDIO_JACK_5PIN2.2, SJ4.2
unnamed: AUDIO_JACK_5PIN2.3, SJ3.2
unnamed: C2.2, C3.2, R3.2, SJ2.2
unnamed: C4.1, R3.1, R4.2
unnamed: C6.2, R5.1
unnamed: C7.2, R6.1
unnamed: C8.2, R7.1
unnamed: C9.1, SJ4.1
unnamed: C10.1, SJ3.1
unnamed: CAN1.1, SJ1.1, U1.6
unnamed: CAN1.2, R12.2, U1.7
unnamed: MICRO_SD1.5, R1.1
unnamed: R8.1, U1.4
unnamed: R11.2, U1.5
unnamed: R12.1, SJ1.2
unnamed: SJ2.3, SJ3.3, SJ4.3

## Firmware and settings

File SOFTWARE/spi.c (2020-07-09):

#include <stdint.h>
#include <unistd.h>
#include <stdio.h>
#include <stdlib.h>
#include <fcntl.h>
#include <sys/ioctl.h>
#include <linux/types.h>
#include <linux/spi/spidev.h>
#include <string.h>


static const char *device = "/dev/spidev2.0";
static uint8_t spiMode = 3;
static uint8_t spiBPW = 8;
static uint32_t spiSpeed = 500000;
static uint16_t spiDelay = 0;

static int spiSendReceive(int spi_fd, uint8_t *TxBuf, int iTxLen, uint8_t *RxBuf, int iRxLen ) {
	int status;
    if( RxBuf == NULL || iRxLen == 0 ){
		
        struct spi_ioc_transfer spi;
        memset( &spi, 0, sizeof spi);
		
		/* 
		Define message parameters.
		Since RxBuf is NULL we what to write. spi.rx_buf should be 0
		*/
        spi.tx_buf = (unsigned long) TxBuf ;
        spi.rx_buf = 0;
        spi.len = iTxLen;
        spi.delay_usecs = spiDelay;
        spi.speed_hz = spiSpeed;
        spi.bits_per_word = spiBPW;
		
		/*
		Send message
		*/
        status = ioctl (spi_fd, SPI_IOC_MESSAGE(1), &spi) ;
        if (status < 0) {
            perror("can't send spi message");
            return -1;
        }
        return status;
    }else{
	
        struct spi_ioc_transfer	spi[2];
        memset(spi, 0, sizeof spi);
    
		/*
		Define message parameters. iTxLen must not be 0
		*/
		spi[0].tx_buf = (unsigned long) TxBuf;
        spi[0].len = iTxLen;
		spi[0].delay_usecs = spiDelay ;
        spi[0].speed_hz = spiSpeed ;
        spi[0].bits_per_word = spiBPW ;
        
		spi[1].rx_buf = (unsigned long) RxBuf;
        spi[1].len = iRxLen;		
        spi[1].delay_usecs = spiDelay ;
        spi[1].speed_hz = spiSpeed ;
        spi[1].bits_per_word = spiBPW ;
        
		/*
		Send the two messages
		*/
		status = ioctl(spi_fd, SPI_IOC_MESSAGE(2), spi);
        if (status < 0) {
            perror("SPI_IOC_MESSAGE");
            return -1;
        }
        return status;
	}
}

int main(int argc, char *argv[]) {

	int fd;
	int ret;
	/*
	Initialize SPI
	*/
	fd = open(device, O_RDWR);
	if (fd < 0){
		perror("can't open device");
		exit(1);
	}
	ret = ioctl(fd, SPI_IOC_WR_MODE, &spiMode);
	if (ret == -1){
		perror("can't set spi mode");
		exit(1);
	}
	ret = ioctl(fd, SPI_IOC_RD_MODE, &spiMode);
	if (ret == -1){
		perror("can't get spi mode");
		exit(1);
	}
	ret = ioctl(fd, SPI_IOC_WR_BITS_PER_WORD, &spiBPW);
	if (ret == -1){
		perror("can't set bits per word");
		exit(1);
	}
	ret = ioctl(fd, SPI_IOC_RD_BITS_PER_WORD, &spiBPW);
	if (ret == -1){
		perror("can't get bits per word");
		exit(1);
	}
	ret = ioctl(fd, SPI_IOC_WR_MAX_SPEED_HZ, &spiSpeed);
	if (ret == -1){
		perror("can't set max speed hz");
		exit(1);
	}
	ret = ioctl(fd, SPI_IOC_RD_MAX_SPEED_HZ, &spiSpeed);
	if (ret == -1){
		perror("can't get max speed hz");
		exit(1);
	}
	printf("spi mode: %d\n", spiMode);
	printf("bits per word: %d\n", spiBPW);
	printf("max speed: %d Hz (%d KHz)\n", spiSpeed, spiSpeed/1000);


	uint8_t TxBuf[1];
	uint8_t RxBuf[10];

	/*
	Make read from register 0x02
	*/
	TxBuf[0] = 0x82;

	/*
	Read the 7 bytes containing data
	*/
	spiSendReceive(fd, TxBuf, 1, RxBuf, 7);

	/*
	Print temperature
	*/
	printf("Temperature: %.1fC\n", RxBuf[6]*0.5 - 30);

	/*
	Convert X, Y, Z
	*/
	uint16_t X, Y, Z;
	X = (RxBuf[1] << 2) | (RxBuf[0] >> 6);
	Y = (RxBuf[3] << 2) | (RxBuf[2] >> 6);
	Z = (RxBuf[5] << 2) | (RxBuf[4] >> 6);

	/*
	Calculate X, Y and Z
	*/
	double AccX, AccY, AccZ;
	AccX = (X & 0x200) ? (0 - (((~X & 0x3FF) + 1) * 0.004)) : (X * 0.004);
	AccY = (Y & 0x200) ? (0 - (((~Y & 0x3FF) + 1) * 0.004)) : (Y * 0.004);
	AccZ = (Z & 0x200) ? (0 - (((~Z & 0x3FF) + 1) * 0.004)) : (Z * 0.004);

	printf("X axis: %.3f\n", AccX);
	printf("Y axis: %.3f\n", AccY);
	printf("Z axis: %.3f\n", AccZ);

	close(fd);
	return 0;
}

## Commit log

2020-07-09 upload Cad files, user manual
    [GBH254SMT-40(B-V-40-LF).stp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]
2020-07-09 schematic pdf
